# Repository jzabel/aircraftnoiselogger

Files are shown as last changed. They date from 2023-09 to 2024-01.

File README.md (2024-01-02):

# Aircraft Noise Logger

## About The Project

A project to collect noise information from flights over a particular location and send to a consolidated backend.
There are three components to this project: 
1/ instructions and code to build and deploy a number of "noise sensors" throughout an area. These internet of things (IOT) sensors are capable of measuring the dB and sending information regarding that measurement to back-end service (in this case Google Cloud) for storage and analysis.
2/ A system to log aircraft overflights over a defined area and store them in Google cloud for analysis
3/ Logic and analysis using both sound and flight data to answer impact questions regarding air traffic and noise

## Logic and Analysis
All data is currently stored in BigQuery in a noise_logging_dataset and an aircraft_reporting_dataset. Each of these datasets share a common key in the form of a timestamp. 

In the noise_logging_observations, the code places entries each second (1Hz) with a key of "reporting_station" and "reporting_timestamp." Each of these keys has a db_report with value.

In the aircraft_reporting_dataset, each aircraft entering the zone of interest is logged into the dataset with keys of time_position, callsign, latitude, longitude, geo_altitude, baro_altitude, and additional information.

A third table stores callsign ("N number") data, plane type, registrant information, etc.

### Questions to answer
Here are the type of questions we are able to answer and visualize with this information. Github issues have been created for each. Each response should attempt to detail date/time, plane (callsign), type of aircraft, db impact, and geo_altitude. Please use the Github issue to coordinate answering them:
1. Number of Flights over Rock Creek Superior by callsign each day with corresponding noise impact.
2. Total number of touch and go operations by plane and by time/date.
3. Noise impact by type of plane and altitude at various measurement points and/or by altitude
4. Planes flying below 500ft over the residential area
5. Planes louder than 60dB over the residential area (frequency, largest impacts, etc.)

Please reach out via an issue to access project data and cloud environment.

## Noise Capture Information
We create a series of noise sensors that log decible levels at 1Hz and send the information back to Google Cloud. The sensors are designed to be run off inexpensive consumer grade hardware including a Raspberry Pi for general processing and connectivity, but purchasing a specifically designed I2C Decibel Sound Level Meter Module for sound processing. This module is calibrated and allows configuration for A-weighted response, averaging time between 125ms and 1000ms, etc. allowing us to exactly match FAA sensing requirements. We deploy each sensor across the neighborhood at various points and are able to log and analyze the data they produce. Our sensors have been running since September 21, 2023.

The loggers are placed outside and can be attached to surfaces by their enclosure. Here are pictures of our sensors:
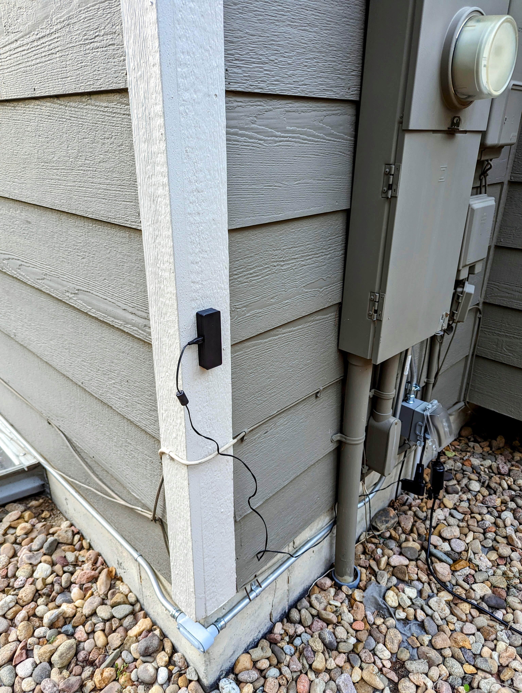
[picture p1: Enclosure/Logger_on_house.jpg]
Logger attached to house

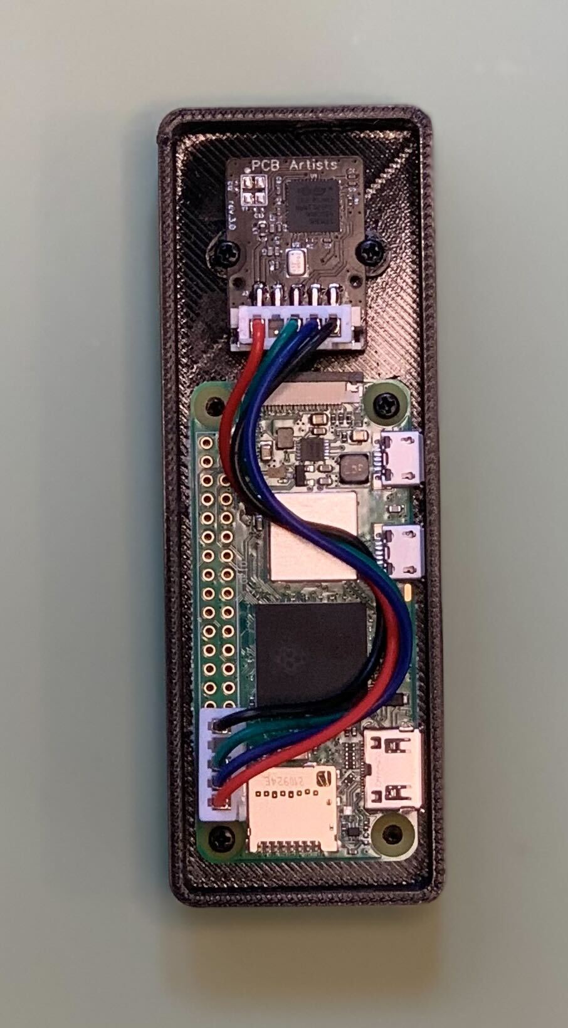
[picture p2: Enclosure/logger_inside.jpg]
Logger internals

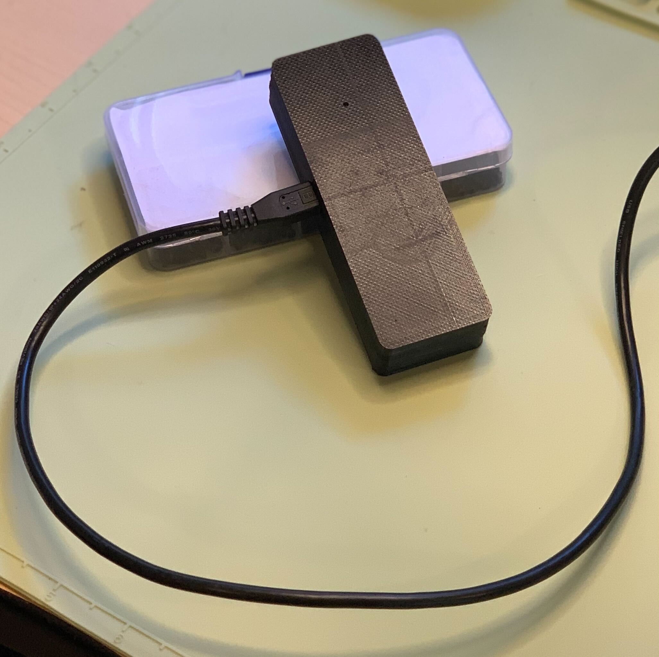
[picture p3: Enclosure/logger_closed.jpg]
Logger enclosure


## Flight Capture Information
To capture flight data, we ultimately decided on a hybrid approach between directly capturing ADSB messages and easier access of an API-based solution. After some digging, we decided to create one central server to publish flight information to a centralized database which all clients, analysts, etc. can access as the truth for plane overflights. To do so, we created multiple Raspberry Pi receivers in the area to capture ADSB messages via Dump1090 and then publish them to the OpenSky API. We have a few in the area, but ultimately only need one to two with good positions / antenna. 

These PIs are responsible for sending ADSB messages to OpenSky. When testing messages, we saw about 1.9M messages in 3 hours from ADSB in our area. As such, relying on OpenSky to consolidate, fill in, update, etc. is very helpful. Because we contribute to OpenSky API, we get increased call limits and we can call data from our own sensors without limits.
** Update - we are currently evaluting alternatives due to poor reliability and uptime from OpenSky Service since mid-November.

As such, one of the Raspberry Pi units is responsible for calling OpenSkyAPI to retrieve flights our ADSB sensors is measuring, do some filtering to include only those in the region of interest, and then publish to our database for analysis.

To get ADSB sensors up and running, you need:
1. Install Dump1090. [This guide is comprehensive in getting this running.](https://stfuandfish.com/2021/10/10/rtl-sdr-dump1090-build-and-install-raspberry-pi-a-video-companion-article/). [This guide](https://vortac.io/2020/06/02/installing-dump1090-on-raspberrypi/) is also helpful if you run into issues.
2. Then sign up to send your ADSB messages to OpenSky for processing. [You can sign up and set your receiver here.](https://opensky-network.org/community/projects/30-dump1090-feeder)

Finally, configure one of your ADSB feeders to query and publish information for processing in the zone of interest. This script is responsible for that publishing:
* [QueryFlight Script](/flight_logger/queryFlights.py) - queries and filters flights in the region of interest, publishing them to Google PubSub and ultimately into Google BigQuery for analysis.

## Noise Sensor Loggers -
See instructions below on how to build and produce sensors capable of monitoring and logging noise measurements:

### Prerequisites

It's recommended that you have some experience with Raspberry Pi and a basic understanding of loading packages and running Python scripts.

**Hardware**

- [Raspberry Pi Zero 2 W](https://www.amazon.com/Raspberry-Zero-Bluetooth-RPi-2W/dp/B09LH5SBPS) or similar 
- Micro SD card ([16GB](https://www.amazon.com/SanDisk-Ultra-SDSQUNS-016G-GN3MN-UHS-I-microSDHC/dp/B074B4P7KD/ref=sr_1_4) minimum, [32GB](https://www.amazon.com/SanDisk-micro-Memory-Card-Tablets/dp/B013TMNKAW/ref=sr_1_11) recommended)
- 5 volt 2 amp power supply
  - E.g. [Power supply AC to USB-A](https://www.amazon.com/ICV-USB-Wall-Charger-Lightweight/dp/B0119BUJDQ/ref=sr_1_19)
  - E.g. [10 feet USB-A to Micro-USB cable](https://www.amazon.com/Amazon-Basics-Charging-Transfer-Gold-Plated/dp/B071S5NTDR/ref=sr_1_3), select length to suit your installation location
- [I2C Decibel Sound Level Meter Module](https://pcbartists.com/product/i2c-decibel-sound-level-meter-module/), with options:
  - Connector: JST-XH Vertical
  - Type: Regular
- 3D printed [Enclosure](Enclosure/README.md)

**Software**

* [run_db_monitoring.py](run_db_monitoring.py) - This is the core script needed that reads in information from the PCBArtist Sound Modules and is responsible for publishing it to the Google Cloud backend. Publishing occurs by pushing data to a Google Pub/Sub channel which in turn then feeds to a consolidated Google BigQuery table.

* [requirements.txt](requirements.txt) - Python libraries necessary to authenticate to GCP and publish Pubsub messages. See notes below as it relates to version information and compatibility with Raspberry Pi OS for Google PubSub python libraries.

* [noise-logger-data-schema.avsc](noise-logger-data-schema.avsc) - Avro schema file specifying the table structure for storing observation data (set in Google PubSub).

### Installation / Getting Started

**Raspberry Pi Setup**
* Create the base operating system using the current version of Raspberry Pi OS (previously Raspbian). Raspberry Pi OS with desktop works great (although is overkill). At development time, we used Kernel 6.1, Debian version 11 (bullseye). [Details on installing here](https://www.raspberrypi.com/software/)

**NOTE:** We recommend installing the "Raspberry Pi OS Lite (32 bit)" image.

Once booted, you need to load libraries and requirements.

### Loading libraries and requirements
#### Update current libraries:
Run `sudo apt-get update && sudo apt-get upgrade`

#### Enable the I2C interface
See: [Enable I2C Interface on the Raspberry Pi](https://www.raspberrypi-spy.co.uk/2014/11/enabling-the-i2c-interface-on-the-raspberry-pi/)

#### Make sure `pip3` is installed.  
If not use the command: `sudo apt-get install python3-pip`

#### Download code from repo
Copy code from this repo into the home `~/` directory of your Pi:
* From a terminal use the following
    - Get the files from the repository: `wget -P ~/ "https://github.com/jzabel/aircraftnoiselogger/archive/master.zip"`
    - Unpack the files into a directory: `unzip master.zip -d aircraftnoiselogger`

#### Setup a virtual environment
Make sure to set up a virtual environment where `<your-env>` is an environment value you set like `aircraft-logger-env`.

```
sudo pip3 install virtualenv
virtualenv --system-site-packages <your-env>
source <your-env>/bin/activate
```

_example:_
    
```
sudo pip3 install virtualenv
virtualenv --system-site-packages aircraft-logger-env 
source aircraft-logger-env/bin/activate
```

* Install required libraries run `sudo pip3 install -r requirements.txt`.
* Contact Jeff for the correct google auth.json key. Transfer the file to the folder that contains run_db_monitoring.py 

#### Adjust your configuration file
The config.json file holds the key values for where to find Google publishing credentials, PubSub topic and projectID, and sets the name of the reporting station. Modify this file to point to the location of your credential file, adjust if necessary the pub/sub topic and project, and set the correct reportingStation name to identify the particular logger.
[Configuration file](config.json)

### Connect PCB Artist Sound Level Board
Connect the board to the appropriate pins on the Raspberry Pi. [See directions here](https://pcbartists.com/product-documentation/accurate-raspberry-pi-decibel-meter/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)

## Usage
* Preferred is to set up a service to keep the process running (see below); however you can test or run the script by running the script in the background: `nohup python3 run_db_monitoring.py &` or by simply calling `python3 run_db_monitoring.py`

## Running the logger as a service on your Pi

The following instructions will configure your Raspberry Pi to run the `run_db_monitoring.py` script as a service.  This service will automatically run as soon as you boot your device.

**_NOTE_**: This configuration assumes you have configured everything above and your `run_db_monitoring.py` script is in the home directory of the `pi` user in the extracted folder named `aircraftnoiselogger`.

### 1. Create a systemd service unit file:

Create a new .service file named `aircraftnoiselogger_script.service`, in the `/etc/systemd/system/` directory:

```
sudo nano /etc/systemd/system/aircraftnoiselogger_script.service
```

### 2. Add the following content to the service unit file:

```
[Unit]
Description=Aircraft Noise Logging Python Script Service
After=network.target

[Service]
ExecStart=/home/pi/aircraftnoiselogger/aircraft-logger-env/bin/python3 /home/pi/aircraftnoiselogger/run_db_monitoring.py
WorkingDirectory=/home/pi/aircraftnoiselogger
Restart=always
User=pi
Environment=PATH=/home/pi/aircraftnoiselogger/aircraft-logger-env/bin
Environment=PYTHONPATH=/home/pi/aircraftnoiselogger

[Install]
WantedBy=multi-user.target
```

Save the file and exit the text editor (in Nano, press `Ctrl+O`, then Enter, and `Ctrl+X`).

### 4. Reload systemd to read the new service file:

```
sudo systemctl daemon-reload
```

### 5. Enable the service to start on boot:

```
sudo systemctl enable aircraftnoiselogger_script.service
```

### 6. Start the service:

```
sudo systemctl start aircraftnoiselogger_script.service
```

To check the status of your service and see if it's running without errors, you can use:

```
sudo systemctl status aircraftnoiselogger_script.service
```

### Proof of Concept Code Snippets
Moved proof of concept and development scrips to the POC folder. The following scripts are no longer used, but left in case helpful.

* [monitor_audio.sh](monitor_audio.sh) - Bash file to access a USB mic and check the root mean square dB level
* [run_monitoring.py](run_monitoring.py) - Runs the bash script and creates a pipe separated entry for timestamp and dB level
* [send_observation_to_cloud.py](send_observation_to_cloud.py) - Takes observation data (currently hardcoded) and publishes a Pubsub message to a topic that is linked to a BigQuery export subscription

### Noise / Audio data

See: [ACCURATE RASPBERRY PI DECIBEL METER](https://pcbartists.com/product-documentation/accurate-raspberry-pi-decibel-meter/)

### Code startup & tricks
You must install Google Cloud & Google Cloud Pubsub libraries; however, you need to use older libraries as there isn't yet dependency support in the Raspberry pi libraries for Google Cloud Pubsub version 2.18.4. To start up, follow directions to set up the Google Python libraries including using virtualenv to set up a virtual environment. This is set automatically in the requirements.txt. If you use current versions, you'll get an error asking for GLIBCXX_3.4.29 in libstdc.so.6.

## Contributing

Contributions are what make the open source community such an amazing place to learn, inspire, and create. Any contributions you make are **greatly appreciated**.

If you have a suggestion that would make this better, please fork the repo and create a pull request. You can also simply open an issue with the tag "enhancement".

## License

Distributed under the MIT License. See [LICENSE](LICENSE) for more information.

## Acknowledgments

[TODO]

* []()
* []()
* []()

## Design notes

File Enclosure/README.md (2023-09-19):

# Aircraft Noise Logger Enclosure

The purpose of this content is to provide designs and 3D printable models for an electronics enclosure for the Aircraft Noise Logger device.

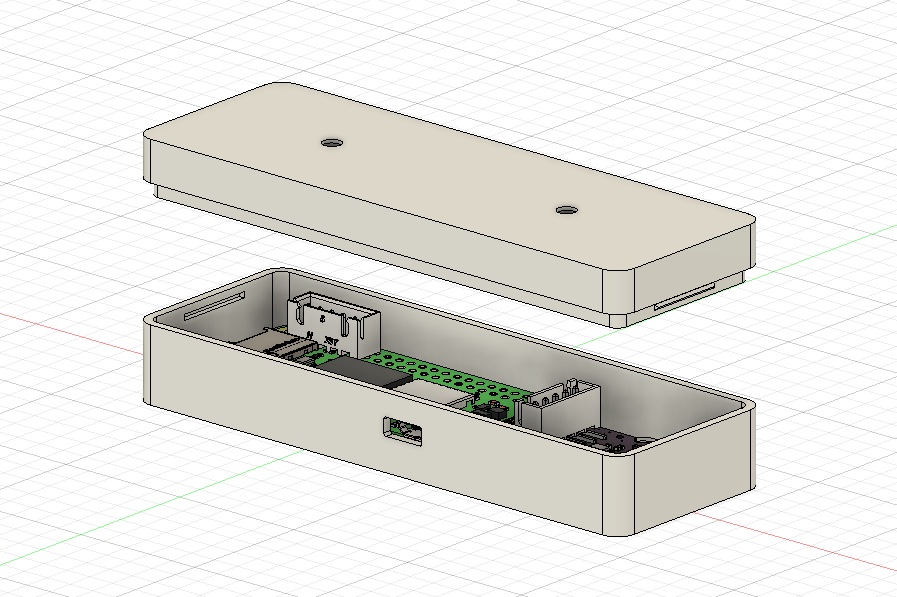
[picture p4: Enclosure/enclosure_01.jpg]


### Built With

[Autodesk Fusion 360](https://www.autodesk.com/products/fusion-360/)

## Getting Started

- Download `noise_logger_base.stl` and `noise_logger_lid.stl` from this repository

### Prerequisites

- 3D printer
- PETG or more durable filament (PLA does not perform well in outdoor environments)
- 4x M2.3x5mm self tapping screws
- 2x M4x20mm self tapping screws

## Usage

For high quality, print at a layer height of .12.

### Mount the electronics to the enclosure base

- Place the Raspberry Pi Zero 2 W on the 4 posts.
- Place 2 of the M2 screws in opposite corner posts and screw the Pi Zero to the enclosure.
- Place the I2C Decibel Sound Level Meter Module on the 3 posts making sure the microphone aligns with the center post.
- Place 2 of the M2 screws on either side of the I2C dB module where the incuts are and screw the module to the enclosure

### Mount the lid

[TODO: more details]

- Using the 2x M4 screws, mount the lid to an ideal outdoor location

### Mount base to lid

- Snap the enclosure base into the enclosure lid.

## Acknowledgments

[michael.crandall@i3creations.com](mailto:michael.crandall@i3creations.com)

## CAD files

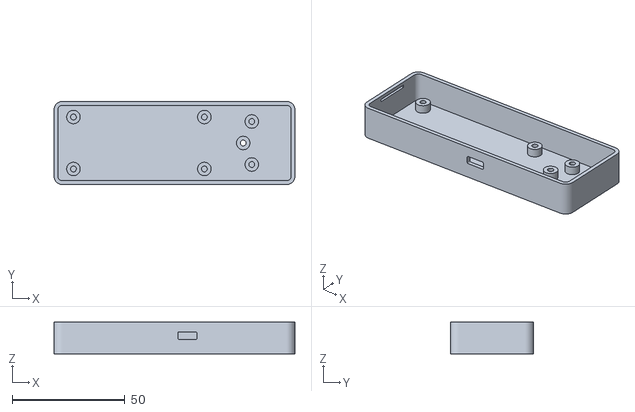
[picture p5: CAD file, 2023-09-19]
Enclosure/noise_logger_base.stl
106.7 x 36.8 x 14.1

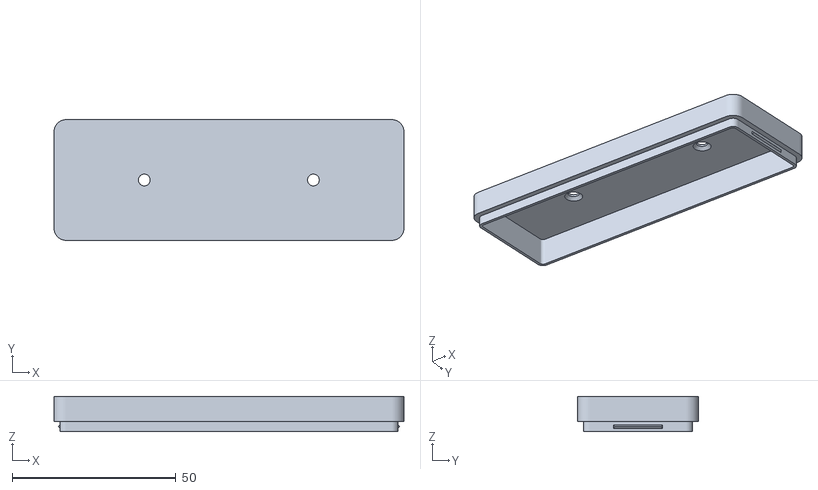
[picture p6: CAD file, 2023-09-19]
Enclosure/noise_logger_lid.stl
106.7 x 36.8 x 10.7

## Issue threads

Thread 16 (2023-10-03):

Create FAA DNL graphs for each sensor

jzabel, 2023-10-03:
Just for example data, add second count (   col B) and manipulate timestamp later
Graph 1 hr Sound Exposure dBA
Convert each second dBA to Pa (col D) (=0.00002*10^(dBA at that second/20))
Calculate average Pa over each hour
Convert average Pa to dBA (=20*LOG(average Pa for that hour /0.00002))
For DNL graph, add 10 dBA to all hours   10p-7a
Show DNL for each hour for each sensor.
Suggestion to do for each day of the week? Not sure if you can average, but at least we can show it by day of the week?

jzabel, 2023-10-05:
Created sql for this:
SELECT
  EXTRACT(hour FROM CAST(reporting_timestamp AS DATETIME)) AS hour,
  AVG((0.00002*POW(10, db_report/20))) AS pascal
FROM superior-noise-loggers.noise_logging_dataset.noise_logging_observations
WHERE reporting_station = "zabel_flint"
AND EXTRACT(DATE FROM CAST(reporting_timestamp AS DATETIME)) > '2023-09-23'
GROUP BY hour
ORDER by hour

Pull out averages in Pascals and then use excel to add the +10 and graph.

jzabel, 2023-10-16:
Closing issue. As we looked deeper, we understood you actually can't calculate DNL65. This post from seatac describes it in detail:
IT’S NOT AN EQUATION
https://seatacnoise.info/dnl65-for-dummies/calculating-dnl65/

In other words, DNL65 is not an equation one can ‘calculate’. DNL65 is to airports what the 1040 Schedule C form 165 (depreciation) is for business owners. Which means that it is not a ‘formula’ or a ‘measurement’. It’s one element of a compliance system which is only manipulated by specialist noise consultants–in the same way that only Certified Public Accountants prepare tax returns for large organizations because they are the only ones who know how to work ‘the system’. (For example, the government charges for access to AEDT for the same reason hospitals charge doctors for access to operating rooms. It’s a tool meant only for professionals.)

The process does consist of taking some measurements, with, you know, microphones; but only to build the initial model (and then perhaps to do occasional checks to confirm that the readings are still relevant.)

The measurements are just inputs to the system. It’s the modeling which is the real information used to make the decisions. Let that sink in for a minute.

Closed 2023-10-16.

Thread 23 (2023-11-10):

Lead particle drift distance

hoopyfrood1006, 2023-11-10:
Add instantaneous and average wind speed-dependent lead particle drift distance estimates to dashboard(s).

Assumptions: HAGL = 500ft; approx. spherical lead particle of radius = 8nm

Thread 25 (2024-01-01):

Use Google Maps API to get altitude of sensor locations

mbaybutt, 2024-01-01:
Determine how to use google maps API to get altitude of the ground at a particular location (i.e. sensor locations) as it relates to the altitude violations to replace the generic/general value for land elevations.

mbaybutt, 2024-01-01:
Related to #22

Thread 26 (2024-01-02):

Capture standard SQL queries

mbaybutt, 2024-01-02:
To help folks get spun up on data analysis, capture the SQL queries that are common (look to Pumble threads).  As appropriate, create a README as well to help folks get up an running with permissions and understand the lay of the land.

mbaybutt, 2024-01-02:
Query associates noise & plane data over a DB threshold:

> SELECT opensky.callsign, opensky.icao24, opensky.baro_altitude, opensky.geo_altitude, opensky.time_position, opensky.latitude, opensky.longitude, TIMESTAMP_SECONDS(CAST(opensky.time_position AS INT)), noise.db_report as noise, noise.reporting_station FROM
  (SELECT callsign, icao24, baro_altitude, geo_altitude, latitude, longitude, time_position,
    ST_INTERSECTS(
       ST_BUFFER(
        ST_GEOGFROMTEXT(
          'POINT(-105.1592234 39.9266306)' #Location of Flints' Noise Logger
        ),
        1000
      ),
      ST_GEOGPOINT(
        SAFE_CAST(longitude as NUMERIC),
        SAFE_CAST(latitude as NUMERIC)
      )
    ) as point_in_poly
  FROM `superior-noise-loggers.aircraft_reporting_dataset.opensky-state-vector-reports`) as opensky
  JOIN `superior-noise-loggers.noise_logging_dataset.noise_logging_observations` as noise
  ON (safe_cast(opensky.time_position as INT64) - 25200) = UNIX_SECONDS(PARSE_TIMESTAMP("%F %H:%M:%E6S", reporting_timestamp))
WHERE
  point_in_poly = true AND db_report > 70 AND EXTRACT(DAYOFYEAR FROM PARSE_TIMESTAMP("%F %H:%M:%E6S", reporting_timestamp)) = 345
AND noise.reporting_station = 'zabel_flint'
ORDER BY
TIMESTAMP_SECONDS(CAST(time_position AS INT)) DESC

mbaybutt, 2024-01-02:
Noise violation:
> SELECT opensky.callsign, opensky.icao24, opensky.baro_altitude, opensky.geo_altitude, noise.reporting_station, opensky.time_position, TIMESTAMP_SECONDS(CAST(opensky.time_position AS INT)), noise.db_report as noise FROM
  (SELECT callsign, icao24, baro_altitude, geo_altitude, latitude, longitude, time_position,
    ST_INTERSECTS(
       ST_BUFFER(
        ST_GEOGFROMTEXT(
          'POINT(-105.15664 39.92287)'
        ),
        900
      ),
      ST_GEOGPOINT(
        SAFE_CAST(longitude as NUMERIC),
        SAFE_CAST(latitude as NUMERIC)
      )
    ) as point_in_poly
  FROM `superior-noise-loggers.aircraft_reporting_dataset.opensky-state-vector-reports`) as opensky
  JOIN `superior-noise-loggers.noise_logging_dataset.noise_logging_observations` as noise
  ON (safe_cast(opensky.time_position as INT64)- 25200) = UNIX_SECONDS(PARSE_TIMESTAMP("%F %H:%M:%E6S", reporting_timestamp))
WHERE
  point_in_poly = true AND db_report > 79 AND UNIX_SECONDS(PARSE_TIMESTAMP("%F %H:%M:%E6S", reporting_timestamp)) > (UNIX_SECONDS(CURRENT_TIMESTAMP())-86400)
ORDER BY
TIMESTAMP_SECONDS(CAST(time_position AS INT)) DESC

mbaybutt, 2024-01-02:
Altitude Violation:
> SELECT opensky.callsign, opensky.icao24, opensky.baro_altitude, opensky.geo_altitude, opensky.latitude, opensky.longitude, opensky.time_position, TIMESTAMP_SECONDS(CAST(opensky.time_position AS INT)), noise.db_report as noise FROM
  (SELECT callsign, icao24, baro_altitude, geo_altitude, latitude, longitude, time_position,
    ST_INTERSECTS(
       ST_BUFFER(
        ST_GEOGFROMTEXT(
          'POINT(-105.15664 39.92287)'
        ),
        850
      ),
      ST_GEOGPOINT(
        SAFE_CAST(longitude as NUMERIC),
        SAFE_CAST(latitude as NUMERIC)
      )
    ) as point_in_poly
  FROM `superior-noise-loggers.aircraft_reporting_dataset.opensky-state-vector-reports`) as opensky
  JOIN `superior-noise-loggers.noise_logging_dataset.noise_logging_observations` as noise
  ON (safe_cast(opensky.time_position as INT64)- 25200) = UNIX_SECONDS(PARSE_TIMESTAMP("%F %H:%M:%E6S", reporting_timestamp))
WHERE
  point_in_poly = true AND safe_cast(opensky.geo_altitude as FLOAT64) < 5901 AND safe_cast(opensky.geo_altitude as FLOAT64) > 0 AND UNIX_SECONDS(PARSE_TIMESTAMP("%F %H:%M:%E6S", reporting_timestamp)) > (UNIX_SECONDS(CURRENT_TIMESTAMP())-86400)
ORDER BY
  TIMESTAMP_SECONDS(CAST(time_position AS INT)) DESC

mbaybutt, 2024-01-02:
All Time Operation Type Counts:
> SELECT (SELECT
 count(operation)
FROM `superior-noise-loggers.aircraft_reporting_dataset.aircraft_operations`
where operation = 'landing') as landing,
(SELECT
 count(operation)
FROM `superior-noise-loggers.aircraft_reporting_dataset.aircraft_operations`
where operation = 'takeoff') as takeoff,
(SELECT
 count(operation)
FROM `superior-noise-loggers.aircraft_reporting_dataset.aircraft_operations`
where operation = 'touch_n_go') as touchandgo,
FROM `superior-noise-loggers.aircraft_reporting_dataset.aircraft_operations`
LIMIT 1

mbaybutt, 2024-01-02:
Recent Airplane T&G count:
> SELECT
  icao_hex, callsign, COUNT(operation) as tgcount
FROM `superior-noise-loggers.aircraft_reporting_dataset.aircraft_operations`
WHERE operation = "touch_n_go" AND $__timeFilter(TIMESTAMP_SECONDS(safe_cast(ops_timestamp as INT64)))
GROUP BY icao_hex, callsign
ORDER BY tgcount DESC

You'll have to edit the timefilter thing here to be SQL, this timeFilter is for Grafana

mbaybutt, 2024-01-02:
Recent Operation List :
> SELECT * FROM `superior-noise-loggers.aircraft_reporting_dataset.aircraft_operations` WHERE $__timeFilter(TIMESTAMP_SECONDS(safe_cast(ops_timestamp as INT64))) ORDER BY ops_timestamp DESC LIMIT 50

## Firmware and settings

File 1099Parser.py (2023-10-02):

#!/usr/bin/env python
# encoding: utf-8

import json
import time
import socket
import datetime
import calendar

dataDir = "/home/pi/rawData"

'''
def getLocation():
        resultVar = None
        while resultVar is None:
                try:
                        locationFile = "/home/pi/currentLocation.json"
                        currentLocation = open(locationFile, "r").read()
                        locationObj = json.loads(currentLocation)
                        resultVar = True
                except:
                        pass

        return locationObj
'''

def mkEpoch(inputDatestamp, inputTimestamp):
	inputDatestamp = inputDatestamp.replace("/", "-")
	inputStr = inputDatestamp + " " + inputTimestamp
	datetimeObj = datetime.datetime.strptime(inputStr, "%Y-%m-%d %H:%M:%S.%f")
	epochVal = calendar.timegm(datetimeObj.timetuple())

	return epochVal


def list2obj(rawList):
	outputObj = {}
	outputObj["messageType"] = rawList[0]
	outputObj["transmissionType"] = rawList[1]
	outputObj["sessionId"] = rawList[2]
	outputObj["aircraftId"] = rawList[3]
	outputObj["hexIdent"] = rawList[4]
	outputObj["flightId"] = rawList[5]
	outputObj["loggedDate"] = rawList[6]
	outputObj["loggedTime"] = rawList[7]
	outputObj["loggedEpoch"] = mkEpoch(str(rawList[6]), str(rawList[7]))
	outputObj["generatedDate"] = rawList[8]
	outputObj["generatedTime"] = rawList[9]
	outputObj["generatedEpoch"] = mkEpoch(str(rawList[8]), str(rawList[9]))
	outputObj["callsign"] = rawList[10]
	outputObj["altitude"] = rawList[11]
	outputObj["groundSpeed"] = rawList[12]
	outputObj["track"] = rawList[13]
	outputObj["lat"] = rawList[14]
	outputObj["lon"] = rawList[15]
	outputObj["verticalRate"] = rawList[16]
	outputObj["squawk"] = rawList[17]
	outputObj["alert"] = rawList[18]
	outputObj["emergency"] = rawList[19]
	outputObj["spi"] = rawList[20]
	outputObj["onGround"] = rawList[21]
	outputObj["parsedTime"] = rawList[22]
	return outputObj


def main():

	# print args.accumulate(args.in)
	count_since_commit = 0
	count_total = 0
	count_failed_connection_attempts = 1

	# open a socket connection
	while count_failed_connection_attempts < 10:
		try:
			s = connect_to_socket("localhost", 30003)
			count_failed_connection_attempts = 1
			print ("Connected to dump1090 broadcast")
			break
		except socket.error:
			count_failed_connection_attempts += 1
			print ("Cannot connect to dump1090 broadcast. Making attempt %s." % (count_failed_connection_attempts))
			time.sleep(5.0)
	else:
		quit()

	data_str = ""

	try:
		entryCnt = 0
		#loop until an exception
		while True:
			#get current time
			cur_time = datetime.datetime.utcnow()
			ds = cur_time.isoformat()
			ts = cur_time.strftime("%H:%M:%S")

			# receive a stream message
			try:
				message = ""
				message = s.recv(10)
				data_str += message.strip("\n")
			except socket.error:
				# this happens if there is no connection and is delt with below
				pass

			if len(message) == 0:
				print (ts, "No broadcast received. Attempting to reconnect")
				time.sleep(args.connect_attempt_delay)
				s.close()

				while count_failed_connection_attempts < args.connect_attempt_limit:
					try:
						s = connect_to_socket(args.location, args.port)
						count_failed_connection_attempts = 1
						print ("Reconnected!")
						break
					except socket.error:
						count_failed_connection_attempts += 1
						print ("The attempt failed. Making attempt %s." % (count_failed_connection_attempts))
						time.sleep(args.connect_attempt_delay)
				else:
					quit()

				continue

			# it is possible that more than one line has been received
			# so split it then loop through the parts and validate

			data = data_str.split("\n")

			for d in data:
				line = d.split(",")
				'''
				#if the line has 22 items, it's valid
				if len(line) == 22:
				'''
					# add the current time to the row
					if len(line[14]) > 2:
						#entryCnt += 1
						epochNow = calendar.timegm(time.gmtime())
						line.append(ds)
						tmpObj = {}
						filePath = dataDir + "/" + str(epochNow) + "-" + line[4] + ".json"
						tmpObj["rawData"] = list2obj(line)
						tmpObj["rxLocation"] = getLocation()
						print tmpObj["rxLocation"]
						try:
							open(filePath, "wb").write(json.dumps(tmpObj))
						except:
                                                        print "Error retrieving receiver location..."
							pass
						#print line
						#print entryCnt

					# since everything was valid we reset the stream message
					data_str = ""
				'''
				#else:
					# the stream message is too short, prepend to the next stream message
					#data_str = d
					#continue
				'''

	except KeyboardInterrupt:
		print ("\n%s Closing connection" % (ts,))
		s.close()

		conn.commit()
		conn.close()
		print (ts, "%s squitters added to your database" % (count_total,))

	except Exception as e:
		print (e)
		quit()

def connect_to_socket(loc,port):
	s = socket.socket(socket.AF_INET, socket.SOCK_STREAM)
	s.connect((loc, port))
	return s


if __name__ == '__main__':
	main()

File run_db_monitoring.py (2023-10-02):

import json
import time
import datetime
import smbus
import sched
from google.cloud import pubsub_v1
from google.oauth2 import service_account

config_filename = "config.json"

# Method to load config file
def load_config(filename):
    try:
        with open(filename, 'r') as config_file:
            config = json.load(config_file)
        return config
    except FileNotFoundError:
        print(f"Config file '{filename}' not found.")
        exit(1)
    except json.JSONDecodeError as e:
        print(f"Error decoding JSON in '{filename}': {e}")
        exit(1)

def publish_data(reporting_obj):
	publisher_client = pubsub_v1.PublisherClient(credentials = credentials_obj)

	pubsub_topic_path = "projects/{project_id}/topics/{pubsub_topic}".format(
		project_id = project_id,
		pubsub_topic = pubsub_topic
	)

	async_future = publisher_client.publish(
		pubsub_topic_path,
		json.dumps(reporting_obj).encode("utf-8")
 	)

	async_future.result()

	return "data published"


def read_db(scheduler):

	device_bus = 1
	device_addr = 0x48
	bus_handler = smbus.SMBus(device_bus)
	recorded_db = bus_handler.read_byte_data(device_addr, 0x0A)
	current_timestamp = str(datetime.datetime.now())

	#schedule the first call
	scheduler.enter(1, 1, read_db, (scheduler,))

	#print ("db is " + str(recorded_db) + ' @ ' + current_timestamp)

	reporting_obj = {
		"reporting_station": reporting_station,
		"reporting_timestamp": current_timestamp,
		"db_report": float(recorded_db)
	}

	publish_data(reporting_obj)

	return current_timestamp, recorded_db


def main():
	try:
		print("Starting up")

		# Execute/schedule 1 second sound readings
		scheduled_sound_read = sched.scheduler(time.time, time.sleep)
		scheduled_sound_read.enter(1, 1, read_db, (scheduled_sound_read,))
		print("Start reading sound levels")
		scheduled_sound_read.run()

	except Exception as e:
		print("encountered an issue - not publishing")
		print(f"An exception occurred: {e}")
		exit(1)


if __name__ == "__main__":
	config = load_config(config_filename)
	credentials_file = config["credentialsFile"]
	credentials_obj = service_account.Credentials.from_service_account_file(credentials_file)
	project_id = config["projectId"]
	pubsub_topic = config["topicId"]
	reporting_station = config["reportingStation"]
	
	main()

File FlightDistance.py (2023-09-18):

# FlightDistance.py>

import numpy as np
import math

# constants
#----------
# https://www.unavco.org/software/geodetic-utilities/geoid-height-calculator/geoid-height-calculator.html
homela = 39.+0./60+0./3600. #  reference longitude (adjust 0s in minutes, seconds)
homelo = -105.-0./60-0./3600. # reference longitude (adjust 0s in minutes, seconds)
homeel = 5600. #ft --> *0.3048 = 1707m **NOT IMPLEMENTED**
geodht = -16.67 #m
orthht = 1723.55 #m
Rearth = 6378100. #m
m2ft  = 3.28084 #ft/m
m2mi  = 0.000621371 #mi/m

# functions
#----------

# projectedDistance
#------------------
# reference
#	https://math.stackexchange.com/questions/833002/distance-between-two-points-in-spherical-coordinates
#
# math
# 	dist = {r^2 + r'2 - 2rr'[sin(theta)sin(theta')cos(phi-phi')+cos(theta)cos(theta')]}^1/2
# 	A = r^2 + r'2 --> 2r^2
# 	B = 2rr' --> 2r^2
# 	C = sin(theta)sin(theta')
# 	D = cos(phi-phi')
# 	E = cos(theta)cos(theta')
# 		--> dist = [A - B*(C*D+E)]^1/2
# 		(1,0deg,0deg)spherical = (0,0,1)cartesian --> phi = 90-latitude

def projectedDistance(lat, lon):
    
	A = 2.*(Rearth+orthht+geodht)**2
	B = A
	C = np.sin(np.radians(homelo))*np.sin(np.radians(lon))
	D = np.cos(np.radians((90-homela)-(90-lat)))
	E = np.cos(np.radians(homelo))*np.cos(np.radians(lon))
	dist = math.sqrt(A - B*(C*D + E))*m2mi

#	print("Projected distance: ", dist)

	return dist;

# lineofsightDistance
#------------------
# reference
#	https://math.stackexchange.com/questions/833002/distance-between-two-points-in-spherical-coordinates
#
# math
# 	dist = {r^2 + r'2 - 2rr'[sin(theta)sin(theta')cos(phi-phi')+cos(theta)cos(theta')]}^1/2
# 	A = r^2 + r'2
# 	B = 2rr'
# 	C = sin(theta)sin(theta')
# 	D = cos(phi-phi')
# 	E = cos(theta)cos(theta')
# 		--> dist = [A - B*(C*D+E)]^1/2
# 		(1,0deg,0deg)spherical = (0,0,1)cartesian --> phi = 90-latitude

def lineofsightDistance(lat, lon, geoalt):

	A = (Rearth+orthht+geodht)**2 + (Rearth+geoalt)**2 # REPLACE BARO ALTITDUE WITH GEO ALTITUDE
	B = 2*(Rearth+orthht+geodht)*(Rearth+geoalt)
	C = np.sin(np.radians(homelo))*np.sin(np.radians(lon))
	D = np.cos(np.radians((90-homela)-(90-lat)))
	E = np.cos(np.radians(homelo))*np.cos(np.radians(lon))
	losdist = math.sqrt(A - B*(C*D + E))*m2ft

#	print("Line of sight distance: ", losdist)

	return losdist;

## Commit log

2023-09-05 Creates a Pubsub message w/ observation data
    Takes obervation data (currently hardcoded) and publishes a Pubsub message to a topic that is linked to a BigQuery export subscription
2023-09-19 Update noise logging with publish
    [run_db_monitoring.py]
2023-09-19 Fix buffer overflow issue
    [run_db_monitoring.py]
2023-09-19 update README, update enclosure info
    [noise_logger_base.stl, noise_logger_lid.stl]
2023-09-19 Actually fix memory leak
    [run_db_monitoring.py]
2023-10-02 Add ability to track flights
2023-10-02 Remove print statement to reduce logsize
2023-10-30 Add files via upload
    Initial release; create branch(es) to fix plots, work on incorporating more efficient ground elevation dataset polling (and interpolation routine), etc.
    [500ft.py, InstantaneousAltitude.py]
2023-12-02 Update to current version of queryFlights for opensky that was modified locally
